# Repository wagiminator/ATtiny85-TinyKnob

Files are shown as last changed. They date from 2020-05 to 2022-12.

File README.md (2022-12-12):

# TinyKnob - Rotary Encoder with USB Interface
TinyKnob is a rotary encoder with a USB interface based on the ATtiny45/85 and the V-USB software-only implementation of USB1.1 devices on AVR microcontrollers (https://www.obdev.at/products/vusb/index.html). The example code implements a volume control knob for PCs which works without installing any driver by acting like a generic HID device.

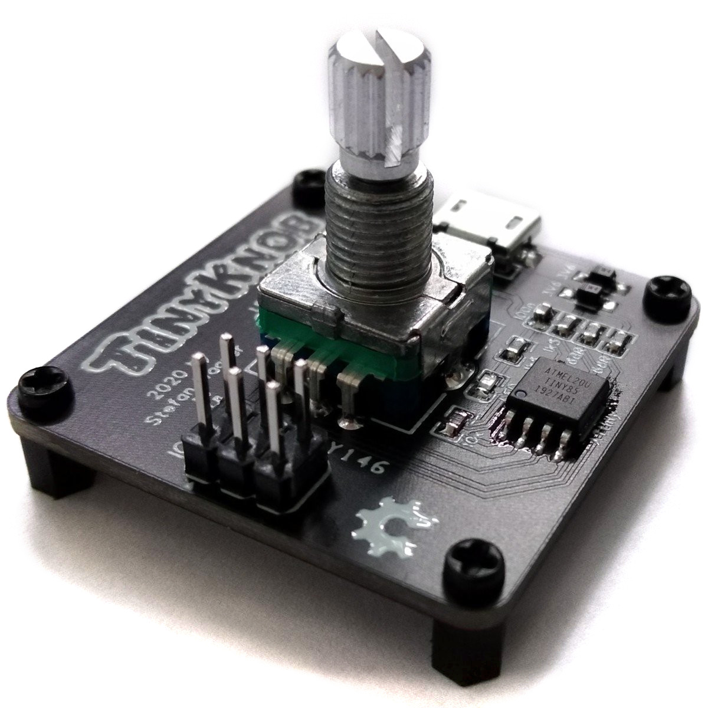
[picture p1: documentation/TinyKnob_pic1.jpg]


# Compiling and Uploading the Firmware
## If using the precompiled hex-file
- Make sure you have installed [avrdude](https://learn.adafruit.com/usbtinyisp/avrdude).
- Connect your programmer to your PC and to the ICSP header on the board.
- Open a terminal.
- Navigate to the folder with the hex-file (software/binaries).
- Execute the following command (if necessary replace "t85" with your chip and "usbasp" with the programmer you use):
  ```
  avrdude -c usbasp -p t85 -U flash:w:tinyknob.hex -U lfuse:w:0xe1:m -U hfuse:w:0xdd:m
  ```

## If using the makefile (Linux/Mac)
- Make sure you have installed [avr-gcc toolchain and avrdude](http://maxembedded.com/2015/06/setting-up-avr-gcc-toolchain-on-linux-and-mac-os-x/).
- Connect your programmer to your PC and to the ICSP header on the board.
- Open a terminal.
- Navigate to the folder with the makefile (software/sources).
- Run `DEVICE=attiny85 PROGRMR=usbasp make install` to compile, burn the fuses and upload the firmware (change DEVICE and PROGRMR accordingly).

# References, Links and Notes
1. [ATtiny25/45/85 Datasheet](https://ww1.microchip.com/downloads/en/DeviceDoc/Atmel-2586-AVR-8-bit-Microcontroller-ATtiny25-ATtiny45-ATtiny85_Datasheet.pdf)
2. [V-USB Info](https://www.obdev.at/products/vusb/index.html)

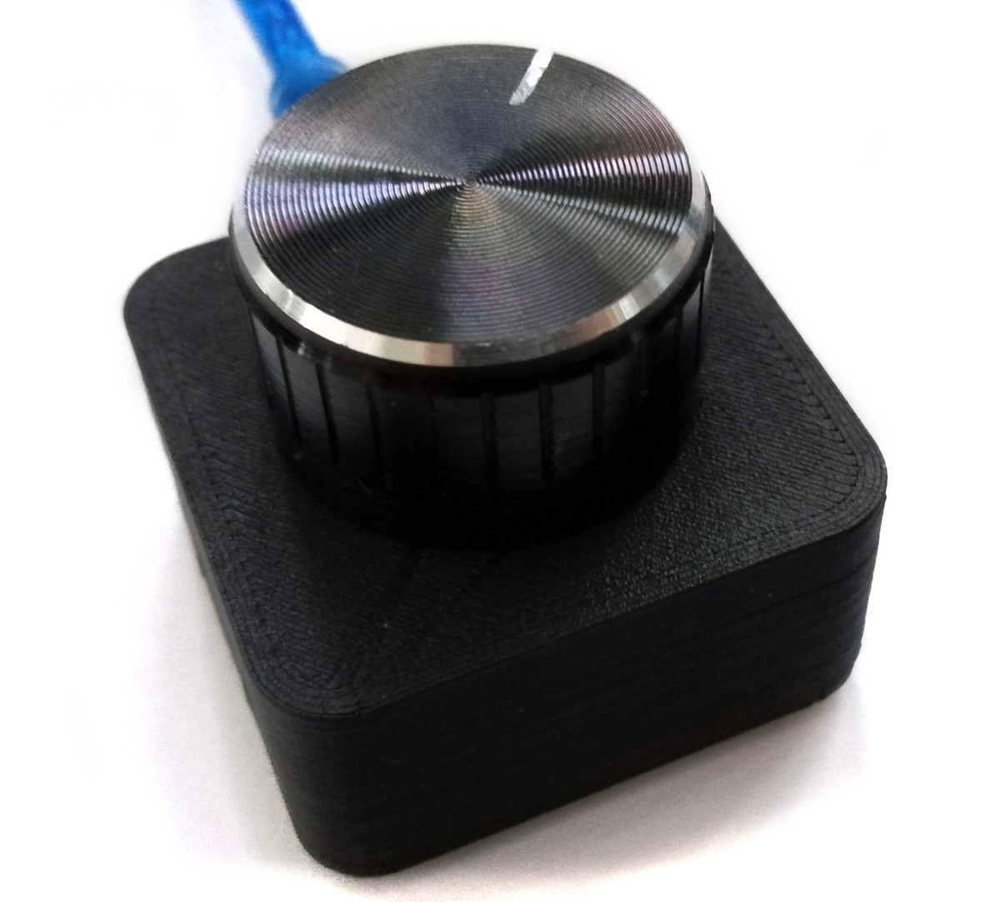
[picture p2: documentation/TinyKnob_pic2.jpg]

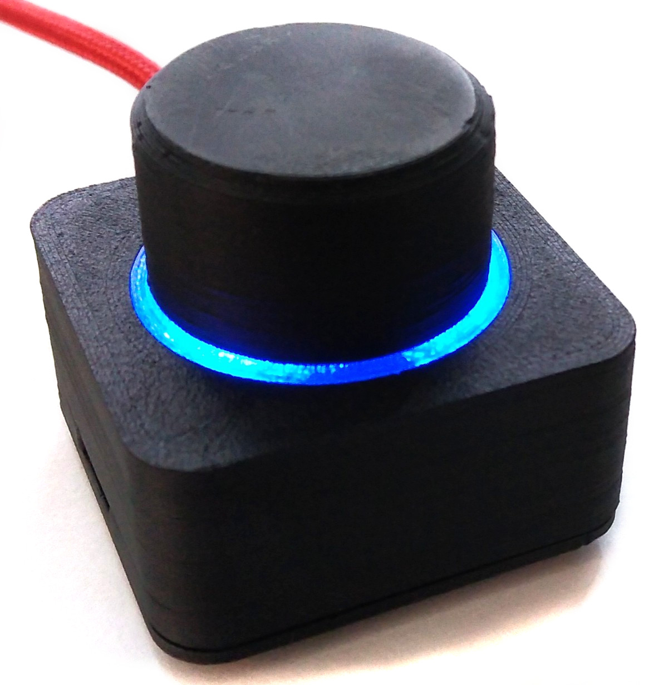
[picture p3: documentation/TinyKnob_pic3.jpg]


# License


This work is licensed under Creative Commons Attribution-ShareAlike 3.0 Unported License. 
(http://creativecommons.org/licenses/by-sa/3.0/)

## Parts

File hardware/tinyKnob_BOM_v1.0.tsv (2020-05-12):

ID | Name | Designator | Footprint | Quantity | Manufacturer Part | Manufacturer | Supplier | Supplier Part | LCSC Assembly
1 | 3V6 | D2,D1 | ZENER-SOD-123 | 2 | MMSZ5230B | CJ | LCSC | C21553 | Yes
2 | 10k | R1 | 0603 | 1 | 0603WAF1002T5E | UniOhm | LCSC | C25804
3 | 1k5 | R6,R4,R5 | 0603 | 3 | 0603WAF1501T5E | UniOhm | LCSC | C22843
4 | 68R | R3,R2 | 0603 | 2 | 0603WAF680JT5E | UniOhm | LCSC | C27592
5 | Rotary Encoder | SW1 | ROTARY_ENCODER | 1 | PEC11R-4015F-S0024 | BOURNS | LCSC | C143789
6 | ATtiny | U1 | SOIC-8_208MIL | 1 | ATTINY85-20SU | MICROCHIP | LCSC | C89852
7 | ICSP-6 | ICSP | ICSP-6 | 1 | ?
8 | LED-0603-BLUE | LED1,LED2 | LED0603 | 2 | 19-217/BHC-ZL1M2RY/3T | EVERLIGHT | LCSC | C72041 | Yes
9 | 100n | C1 | 0603 | 1 | CC0603KRX7R9BB104 | YAGEO | LCSC | C14663
10 | 47u | C2 | 1206 | 1 | CL31A476MQHNNNE | SAMSUNG | LCSC | C68361
11 | Micro USB | USB | MICRO-USB-16 | 1 | - | Boom Precision Elec | LCSC | C21377

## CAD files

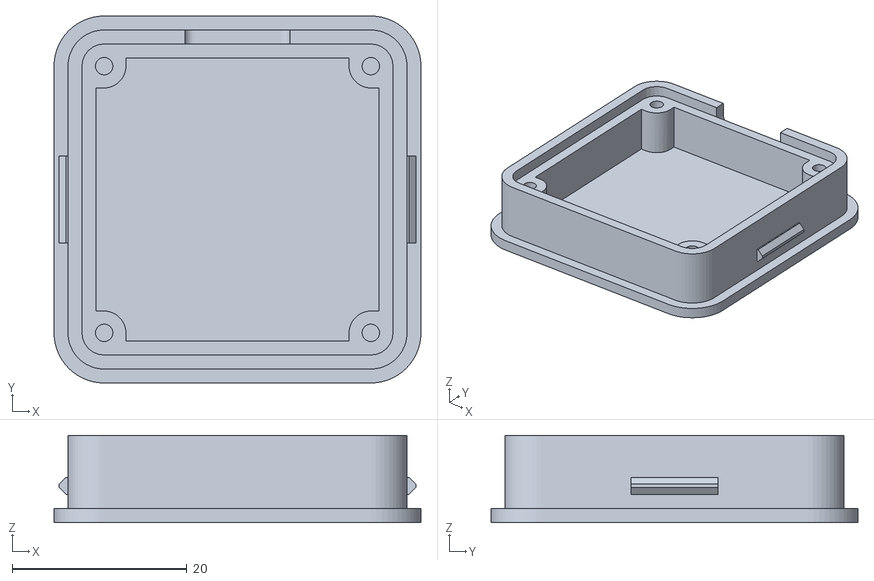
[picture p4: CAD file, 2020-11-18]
3dprint/tinyKnob_case_3dprint_v1.1/TinyKnob_case_bottom_v1.1.stl
42.0 x 42.0 x 10.0

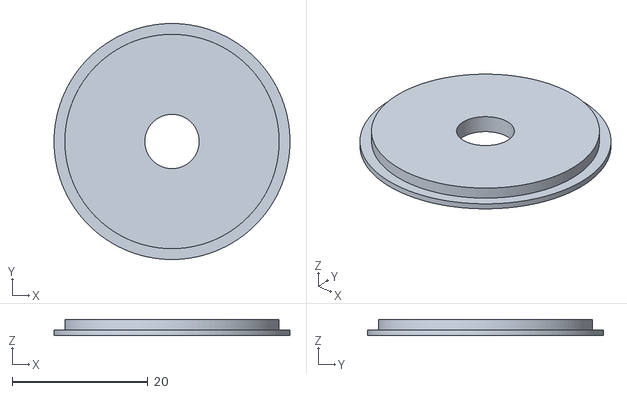
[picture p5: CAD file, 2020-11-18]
3dprint/tinyKnob_case_3dprint_v1.1/TinyKnob_case_ring_v1.1.stl
34.8 x 34.8 x 2.40

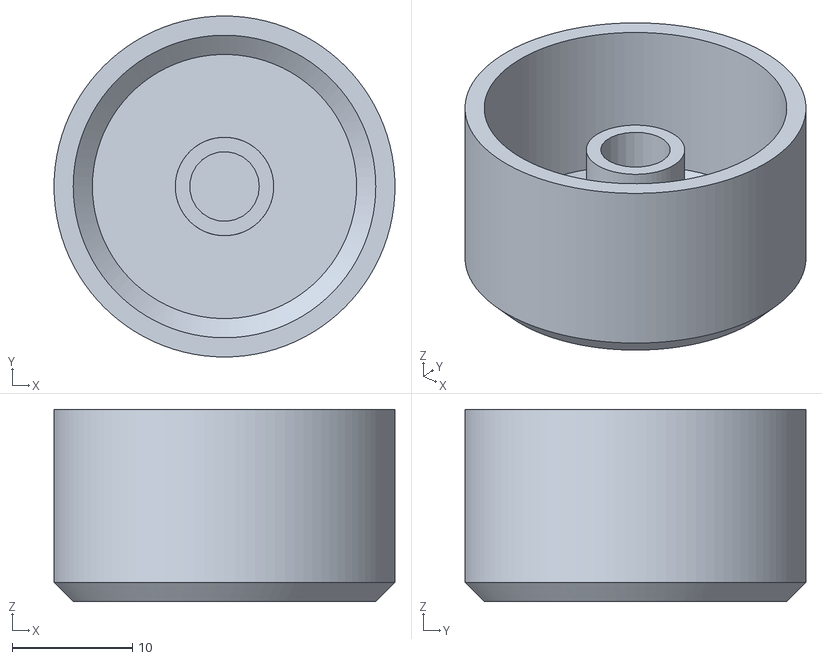
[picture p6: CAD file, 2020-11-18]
3dprint/tinyKnob_case_3dprint_v1.1/TinyKnob_case_knob_v1.1.stl
28.4 x 28.4 x 16.0

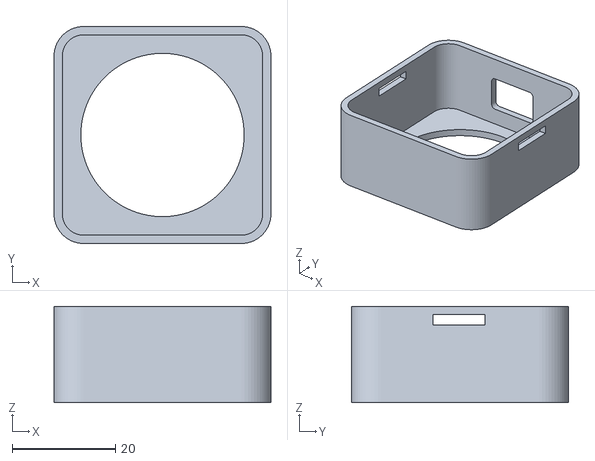
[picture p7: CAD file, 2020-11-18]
3dprint/tinyKnob_case_3dprint_v1.1/TinyKnob_case_top_v1.1.stl
42.0 x 42.0 x 18.6

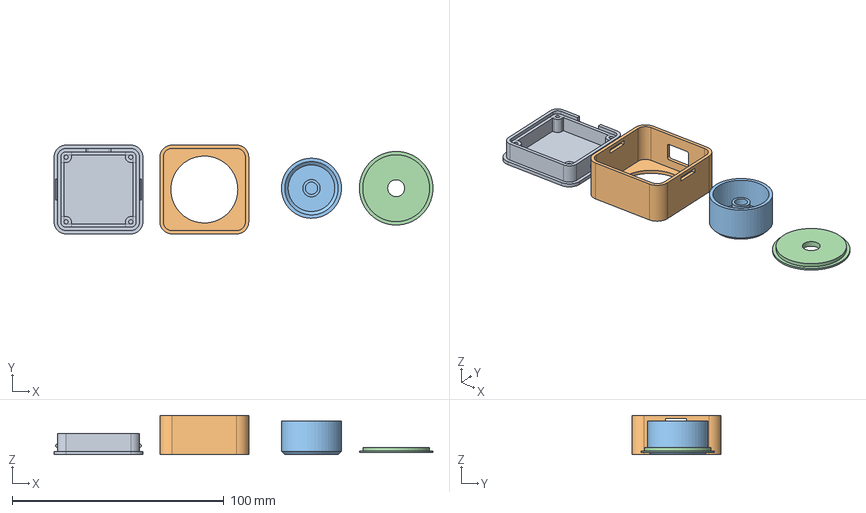
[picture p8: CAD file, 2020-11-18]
3dprint/tinyKnob_case_3dprint_v1.1/TinyKnob_case_v1.1.fcstd
179.0 x 42.0 x 18.6 mm
Boden
Deckel
Knob
LED-Ring

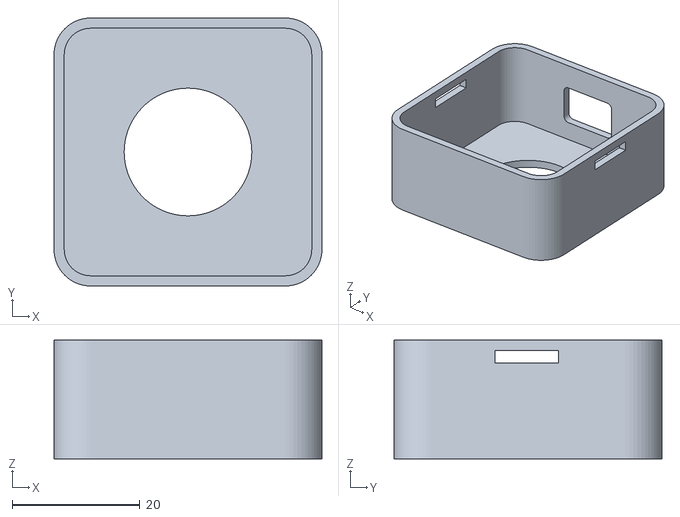
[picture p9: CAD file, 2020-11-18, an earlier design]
3dprint/tinyKnob_case_3dprint_v1.0/TinyKnob_case_top.stl
42.0 x 42.0 x 18.6

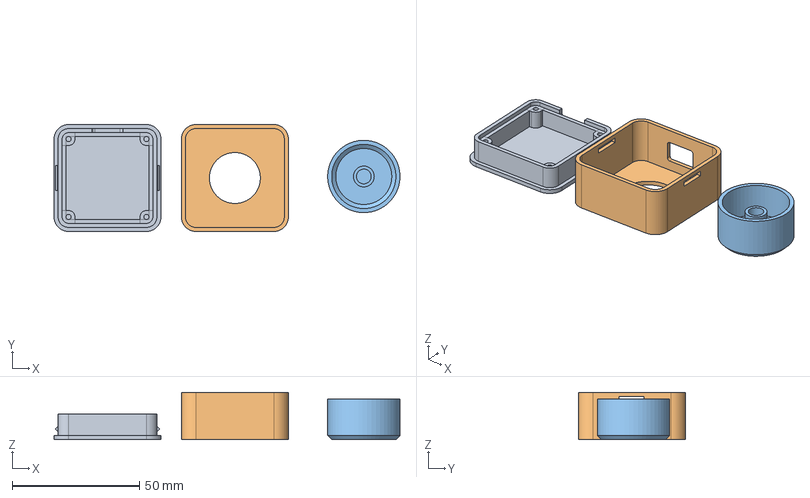
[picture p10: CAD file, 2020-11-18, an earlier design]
3dprint/tinyKnob_case_3dprint_v1.0/TinyKnob.fcstd
135.8 x 42.0 x 18.6 mm
Boden
Deckel
Knob

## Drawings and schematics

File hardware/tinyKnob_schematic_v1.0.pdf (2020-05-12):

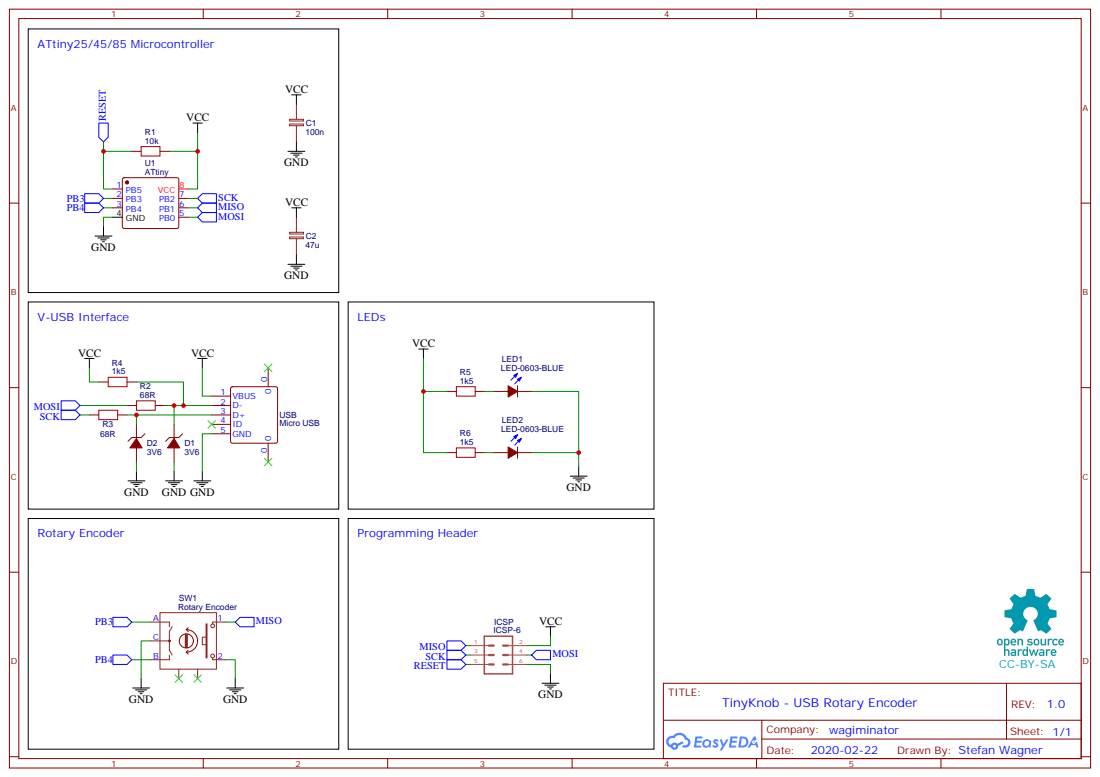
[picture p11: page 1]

Drawn By: Stefan Wagner

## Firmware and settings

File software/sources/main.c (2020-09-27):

// tinyKnob
//
// USB volume control for ATtiny45/85 using rotary encoder
// and v-usb interface based on several examples from 
// https://www.obdev.at/products/vusb/projects.html
//
//                         +-\/-+
// --------- A0 (D5) PB5  1|    |8  Vcc
// ENC A --- A3 (D3) PB3  2|    |7  PB2 (D2) A1 --- USB+
// ENC B --- A2 (D4) PB4  3|    |6  PB1 (D1) ------ ENC SW
//                   GND  4|    |5  PB0 (D0) ------ USB-
//                         +----+    
//
// 2020 by Stefan Wagner 
// Project Files (EasyEDA): https://easyeda.com/wagiminator
// Project Files (Github):  https://github.com/wagiminator
// License: http://creativecommons.org/licenses/by-sa/3.0/


// CPU clock
#define F_CPU       16500000      // 16.5 MHz

// Libraries
#include <avr/io.h>
#include <avr/wdt.h>
#include <avr/interrupt.h>
#include <avr/pgmspace.h>
#include <util/delay.h>
#include "usbdrv.h"
#include "oddebug.h"

// Rotary encoder pins
#define ENC_SW      0b00000010    // PB1
#define ENC_A       0b00001000    // PB3
#define ENC_B       0b00010000    // PB4

// Keyboard codes
#define VOLUMEMUTE  0xE2          // Keyboard Volume Mute
#define VOLUMEUP    0xE9          // Keyboard Volume Up
#define VOLUMEDOWN  0xEA          // Keyboard Volume Down

// USB report descriptor
PROGMEM const char usbHidReportDescriptor[USB_CFG_HID_REPORT_DESCRIPTOR_LENGTH] = {
  0x05, 0x0c,           // USAGE_PAGE (Consumer Devices)
  0x09, 0x01,           // USAGE (Consumer Control)
  0xa1, 0x01,           // COLLECTION (Application)
  0x85, 0x01,           //   REPORT_ID (1)
  0x19, 0x00,           //   USAGE_MINIMUM (Unassigned)
  0x2a, 0x3c, 0x02,     //   USAGE_MAXIMUM (AC Format)
  0x15, 0x00,           //   LOGICAL_MINIMUM (0)
  0x26, 0x3c, 0x02,     //   LOGICAL_MAXIMUM (572)
  0x95, 0x01,           //   REPORT_COUNT (1)
  0x75, 0x10,           //   REPORT_SIZE (16)
  0x81, 0x00,           //   INPUT (Data,Var,Abs)
  0xc0                  // END_COLLECTION
};

// Variables
static uchar reportBuffer[3] = {1,0,0}; // buffer for HID reports
static uchar idleRate;                  // in 4 ms units
static uchar currentKey;                // current key to be sent
static uchar isSwitchPressed = 0;       // state of rotary encoder switch

// Check rotary encoder
static void checkEncoder(void) {
  currentKey = 0;
  // Encoder turned ?
  if (!(PINB & ENC_A)) {
    // Clockwise ?
    if (PINB & ENC_B) currentKey = VOLUMEUP;
    else              currentKey = VOLUMEDOWN;
    // Wait until next detent
    while (!(PINB & ENC_A)) _delay_ms(5);
  } else {
    // Mute button previously pressed ?
    if (!isSwitchPressed && !(PINB & ENC_SW)) {
      currentKey = VOLUMEMUTE;
      isSwitchPressed = 1;
      _delay_ms(5);
    } else if (isSwitchPressed && (PINB & ENC_SW)) {
      isSwitchPressed = 0;
      _delay_ms(5);
    }
  }
}

uchar usbFunctionSetup(uchar data[8]) {
  usbRequest_t *rq = (void *)data;
  usbMsgPtr = reportBuffer;
  if ((rq->bmRequestType & USBRQ_TYPE_MASK) == USBRQ_TYPE_CLASS){
    if (rq->bRequest == USBRQ_HID_GET_REPORT) { 
      return sizeof(reportBuffer);
    } else if (rq->bRequest == USBRQ_HID_GET_IDLE) {
      usbMsgPtr = &idleRate;
      return 1;
    } else if (rq->bRequest == USBRQ_HID_SET_IDLE) {
      idleRate = rq->wValue.bytes[1];
    }
  }
  return 0;
}

// Oscillator calibration
static void calibrateOscillator(void) {
  uchar step = 128;
  uchar trialValue = 0, optimumValue;
  int   x, optimumDev, targetValue = (unsigned)(1499 * (double)F_CPU / 10.5e6 + 0.5);

  do {
    OSCCAL = trialValue + step;
    x = usbMeasureFrameLength();
    if (x < targetValue) trialValue += step;
    step >>= 1;
  } while(step > 0);

  optimumValue = trialValue;
  optimumDev = x;
  for (OSCCAL = trialValue - 1; OSCCAL <= trialValue + 1; OSCCAL++) {
    x = usbMeasureFrameLength() - targetValue;
    if (x < 0) x = -x;
    if (x < optimumDev) {
      optimumDev = x;
      optimumValue = OSCCAL;
    }
  }
  OSCCAL = optimumValue;
}

void usbEventResetReady(void) {
  calibrateOscillator();
}

int main(void) {
  usbInit();
  usbDeviceDisconnect();
  uchar i = 0;
  while(--i) {
    wdt_reset();
    _delay_ms(1);
  }
  usbDeviceConnect();
  wdt_enable(WDTO_1S);

  // turn on internal pull-up resistors for rotary encoder
  PORTB |= ENC_A | ENC_B | ENC_SW;

  sei();

  while(1) {
    wdt_reset();
    usbPoll();
    checkEncoder();
    if(usbInterruptIsReady() && (reportBuffer[1] != currentKey)) {
      reportBuffer[1] = currentKey;
      usbSetInterrupt(reportBuffer, sizeof(reportBuffer));
    }
  }
  return 0;
}

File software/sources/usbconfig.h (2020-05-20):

/* Name: usbconfig.h
 * Project: AVR USB driver
 * Author: Christian Starkjohann
 * Creation Date: 2007-06-23
 * Tabsize: 4
 * Copyright: (c) 2007 by OBJECTIVE DEVELOPMENT Software GmbH
 * License: GNU GPL v2 (see License.txt) or proprietary (CommercialLicense.txt)
 * This Revision: $Id: usbconfig.h 537 2008-02-28 21:13:01Z cs $
 */

#ifndef __usbconfig_h_included__
#define __usbconfig_h_included__

/* ---------------------------- Hardware Config ---------------------------- */

#define USB_CFG_IOPORTNAME      B
/* This is the port where the USB bus is connected. When you configure it to
 * "B", the registers PORTB, PINB and DDRB will be used.
 */
#define USB_CFG_DMINUS_BIT      0
/* This is the bit number in USB_CFG_IOPORT where the USB D- line is connected.
 * This may be any bit in the port.
 */
#define USB_CFG_DPLUS_BIT       2
/* This is the bit number in USB_CFG_IOPORT where the USB D+ line is connected.
 * This may be any bit in the port. Please note that D+ must also be connected
 * to interrupt pin INT0!
 */
#define USB_CFG_CLOCK_KHZ       (F_CPU/1000)
/* Clock rate of the AVR in MHz. Legal values are 12000, 16000 or 16500.
 * The 16.5 MHz version of the code requires no crystal, it tolerates +/- 1%
 * deviation from the nominal frequency. All other rates require a precision
 * of 2000 ppm and thus a crystal!
 * Default if not specified: 12 MHz
 */

/* ----------------------- Optional Hardware Config ------------------------ */

/* #define USB_CFG_PULLUP_IOPORTNAME   D */
/* If you connect the 1.5k pullup resistor from D- to a port pin instead of
 * V+, you can connect and disconnect the device from firmware by calling
 * the macros usbDeviceConnect() and usbDeviceDisconnect() (see usbdrv.h).
 * This constant defines the port on which the pullup resistor is connected.
 */
/* #define USB_CFG_PULLUP_BIT          4 */
/* This constant defines the bit number in USB_CFG_PULLUP_IOPORT (defined
 * above) where the 1.5k pullup resistor is connected. See description
 * above for details.
 */

/* --------------------------- Functional Range ---------------------------- */

#define USB_CFG_HAVE_INTRIN_ENDPOINT    1
/* Define this to 1 if you want to compile a version with two endpoints: The
 * default control endpoint 0 and an interrupt-in endpoint 1.
 */
#define USB_CFG_HAVE_INTRIN_ENDPOINT3   0
/* Define this to 1 if you want to compile a version with three endpoints: The
 * default control endpoint 0, an interrupt-in endpoint 1 and an interrupt-in
 * endpoint 3. You must also enable endpoint 1 above.
 */
#define USB_CFG_IMPLEMENT_HALT          0
/* Define this to 1 if you also want to implement the ENDPOINT_HALT feature
 * for endpoint 1 (interrupt endpoint). Although you may not need this feature,
 * it is required by the standard. We have made it a config option because it
 * bloats the code considerably.
 */
#define USB_CFG_INTR_POLL_INTERVAL      10
/* If you compile a version with endpoint 1 (interrupt-in), this is the poll
 * interval. The value is in milliseconds and must not be less than 10 ms for
 * low speed devices.
 */
#define USB_CFG_IS_SELF_POWERED         0
/* Define this to 1 if the device has its own power supply. Set it to 0 if the
 * device is powered from the USB bus.
 */
#define USB_CFG_MAX_BUS_POWER           50
/* Set this variable to the maximum USB bus power consumption of your device.
 * The value is in milliamperes. [It will be divided by two since USB
 * communicates power requirements in units of 2 mA.]
 */
#define USB_CFG_IMPLEMENT_FN_WRITE      0
/* Set this to 1 if you want usbFunctionWrite() to be called for control-out
 * transfers. Set it to 0 if you don't need it and want to save a couple of
 * bytes.
 */
#define USB_CFG_IMPLEMENT_FN_READ       0
/* Set this to 1 if you need to send control replies which are generated
 * "on the fly" when usbFunctionRead() is called. If you only want to send
 * data from a static buffer, set it to 0 and return the data from
 * usbFunctionSetup(). This saves a couple of bytes.
 */
#define USB_CFG_IMPLEMENT_FN_WRITEOUT   0
/* Define this to 1 if you want to use interrupt-out (or bulk out) endpoint 1.
 * You must implement the function usbFunctionWriteOut() which receives all
 * interrupt/bulk data sent to endpoint 1.
 */
#define USB_CFG_HAVE_FLOWCONTROL        0
/* Define this to 1 if you want flowcontrol over USB data. See the definition
 * of the macros usbDisableAllRequests() and usbEnableAllRequests() in
 * usbdrv.h.
 */
#ifndef __ASSEMBLER__
extern void usbEventResetReady(void);
#endif
#define USB_RESET_HOOK(isReset)             if(!isReset){usbEventResetReady();}
/* This macro is a hook if you need to know when an USB RESET occurs. It has
 * one parameter which distinguishes between the start of RESET state and its
 * end.
 */
#define USB_CFG_HAVE_MEASURE_FRAME_LENGTH   1
/* define this macro to 1 if you want the function usbMeasureFrameLength()
 * compiled in. This function can be used to calibrate the AVR's RC oscillator.
 */
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

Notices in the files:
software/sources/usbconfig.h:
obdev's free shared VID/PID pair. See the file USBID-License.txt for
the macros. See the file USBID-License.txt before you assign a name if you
